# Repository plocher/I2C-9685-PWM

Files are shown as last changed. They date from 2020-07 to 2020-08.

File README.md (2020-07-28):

# I2C-LEDStripDriver
## License: CERN Open Hardware Licence v1.2

I2C 16 channel PWM Driver based on a PCA9685 

The PCA9685 is an I2C-bus controlled 16-channel LED controller optimized for Red/Green/Blue/Amber (RGBA) color backlighting applications.  It can also be used to control Servos.
Each output has its own 12-bit resolution (4096 steps) fixed frequency individual PWM controller

This design, when used in conjunction with the IO4-LED_STRIP driver board, drives RGB + "white" LED strips - I use one set for backdrop lighting (dawn and dusk sunsets...) and the other for overhead (sunlight) valence illumination.

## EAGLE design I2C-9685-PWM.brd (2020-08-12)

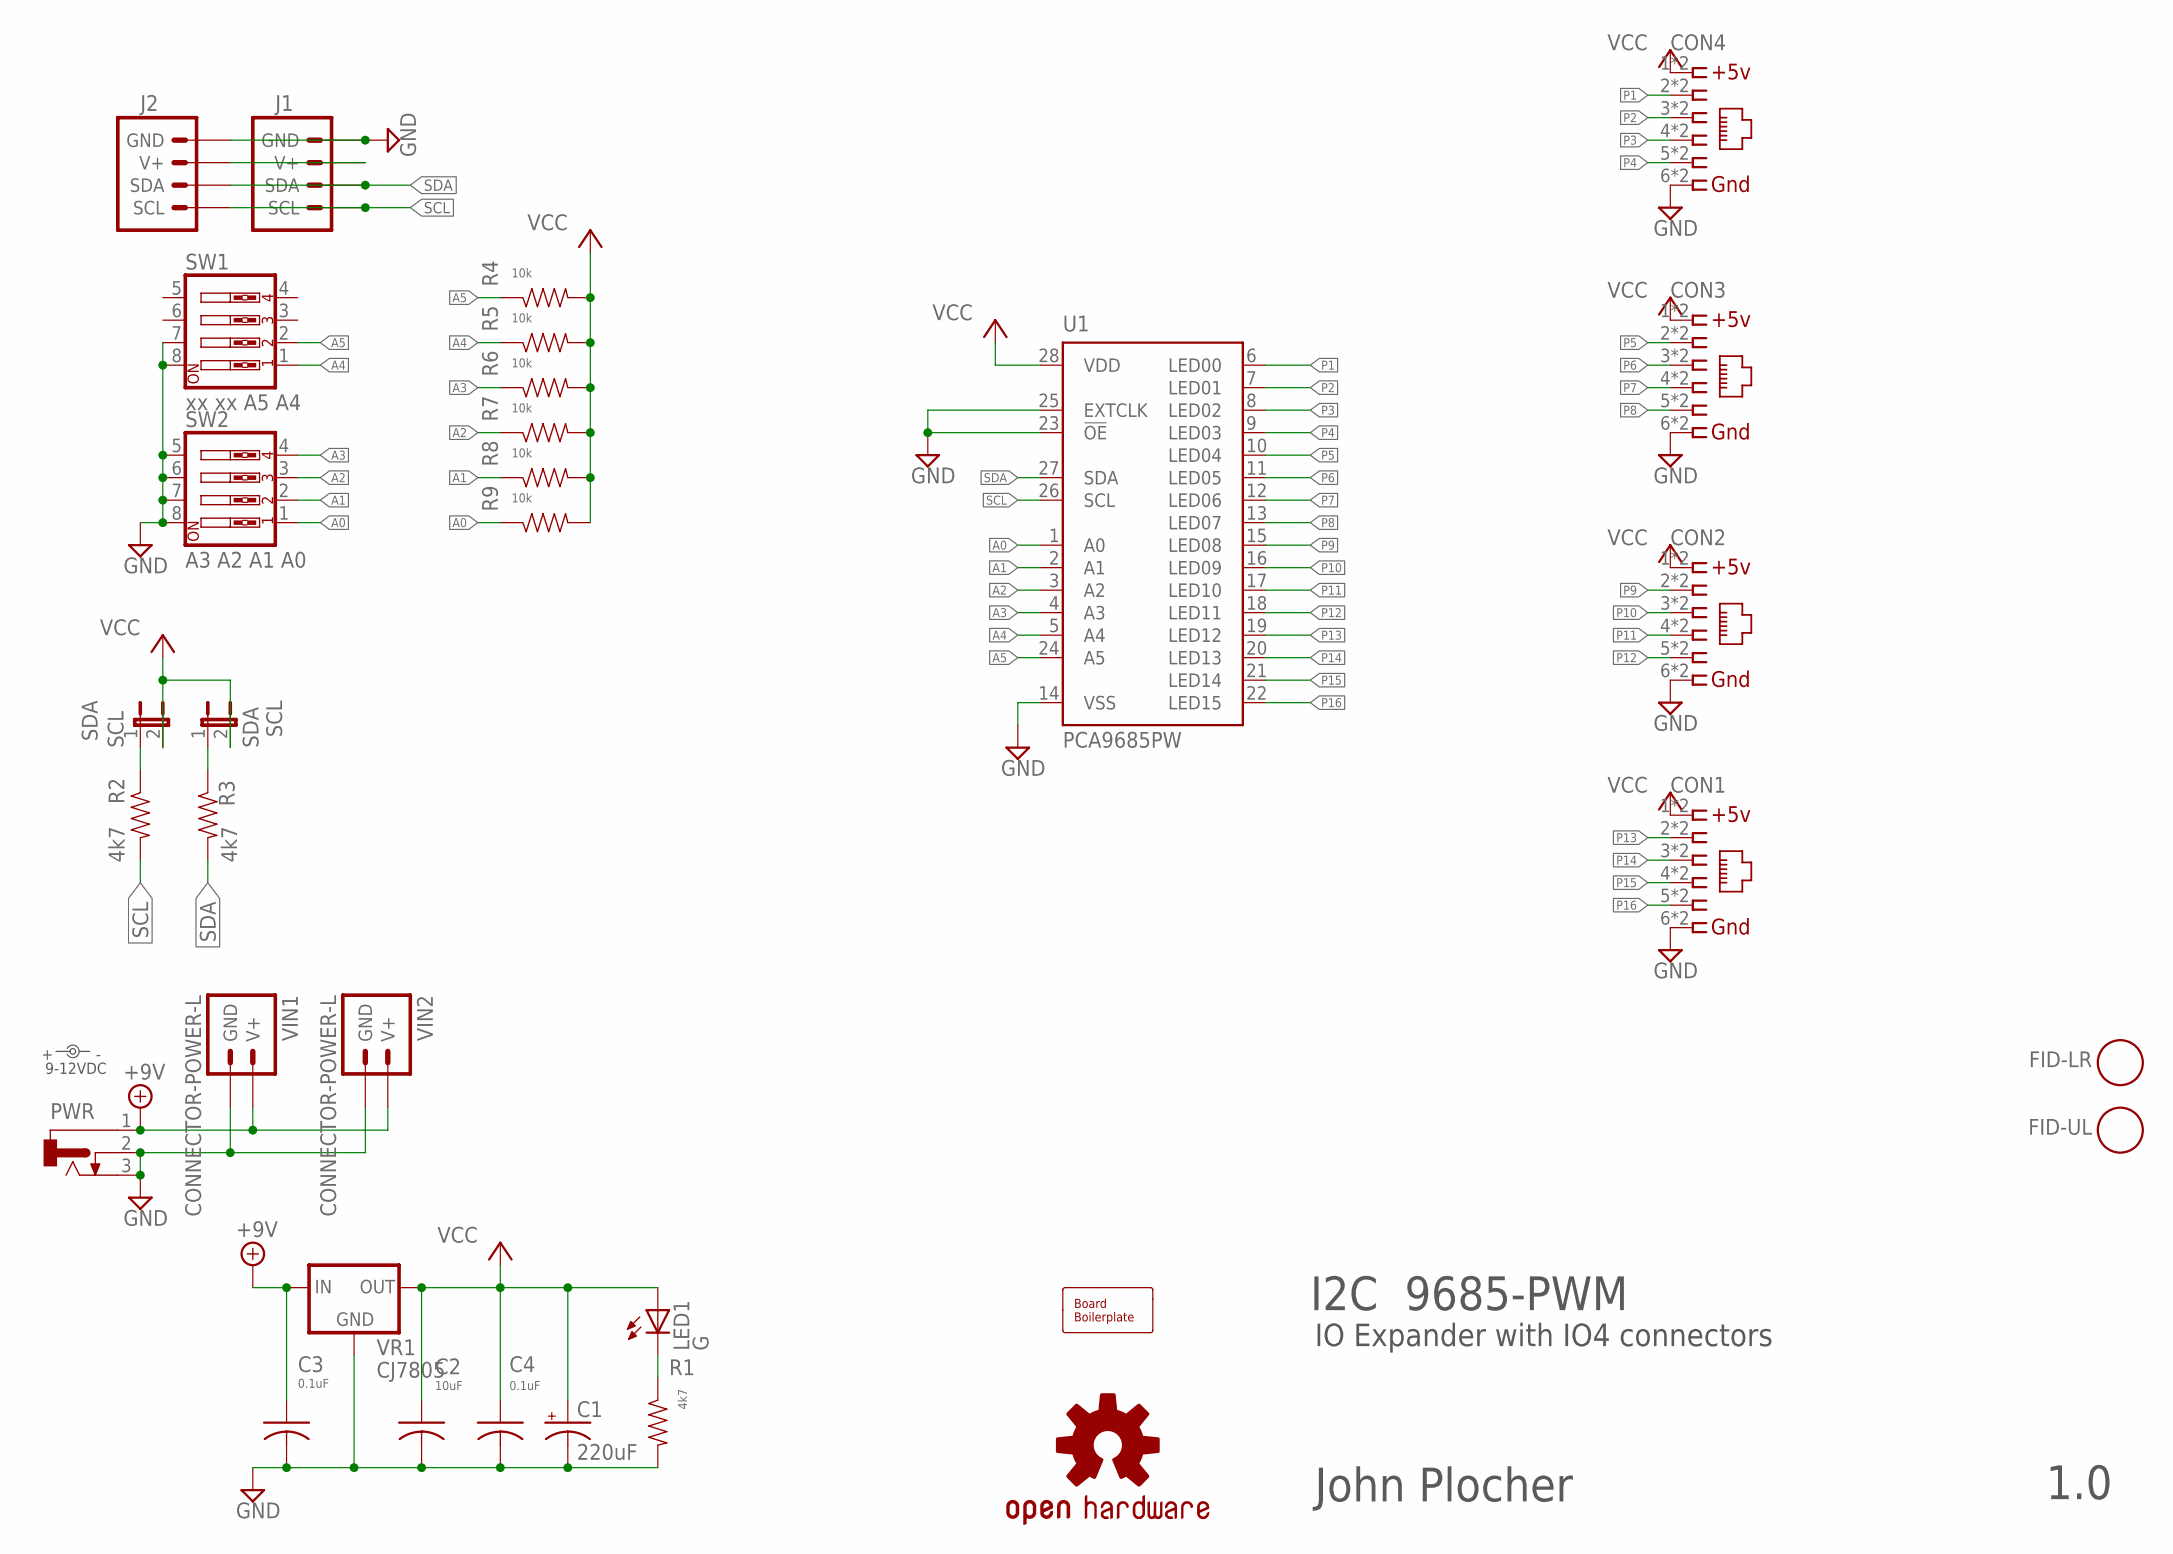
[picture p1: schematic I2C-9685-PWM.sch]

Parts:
BOARD1: BOARD80X100-IOB; BOARD-DINRAIL-3.17IN-IOB
C1: 220uF; 0810-CAP
C2: 10uF; 0805-CAP
C3, C4: 0.1uF; 0805-CAP
CON1, CON2, CON3, CON4: CONNECTOR-IO4IPINS; RJ24-INVERTED-PINS
FID-LR: FIDUCIAL; FIDUCIAL_1MM
FID-UL: FIDUCIAL; FIDUCIAL_1MM
J1, J2: CONNECTOR-I2CLEFT; I2C-L
LED1: G; 0603-LED
PWR: CONNECTOR-DC-POWER-RA; DCJ0202
R1, R2, R3: 4k7; 0603-RES
R4, R5, R6, R7, R8, R9: 10k; 0603-RES
SCL: SDA; 1X02_LOCK
SDA: SCL; 1X02_LOCK
SW1: xx xx A5 A4; EDG-04
SW2: A3 A2 A1 A0; EDG-04
U1: PCA9685PW; TSSOP28
U$1: OSHW-LOGOL; OSHW-LOGO-L
VIN: 9-12VDC; PWR_LABEL
VIN1, VIN2: CONNECTOR-POWER-L; POWER-R2
VR1: CJ7805; TO-252

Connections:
+9V: C3.1, PWR.1, VIN1.V+, VIN1.V+@1 (V+), VIN1.V+@2 (V+), VIN1.V+@3 (V+), VIN2.V+, VIN2.V+@1 (V+), VIN2.V+@2 (V+), VIN2.V+@3 (V+), VR1.1 (IN)
A0: R9.1, SW2.1, U1.1 (A0)
A1: R8.1, SW2.2, U1.2 (A1)
A2: R7.1, SW2.3, U1.3 (A2)
A3: R6.1, SW2.4, U1.4 (A3)
A4: R5.1, SW1.1, U1.5 (A4)
A5: R4.1, SW1.2, U1.24 (A5)
GND: C1.-, C2.2, C3.2, C4.2, CON1.6, CON1.6@1 (6), CON2.6, CON2.6@1 (6), CON3.6, CON3.6@1 (6), CON4.6, CON4.6@1 (6), J1.GND, J1.GND@1 (GND), J2.GND, J2.GND@1 (GND), PWR.2, PWR.3, R1.2, SW1.7, SW1.8, SW2.5, SW2.6, SW2.7, SW2.8, U1.14 (VSS), U1.23 (!OE), U1.25 (EXTCLK), VIN1.GND, VIN1.GND@1 (GND), VIN1.GND@2 (GND), VIN1.GND@3 (GND), VIN2.GND, VIN2.GND@1 (GND), VIN2.GND@2 (GND), VIN2.GND@3 (GND), VR1.2 (GND)
unnamed: LED1.C, R1.1
unnamed: R3.1, SCL.1
unnamed: R2.1, SDA.1
P1: CON4.2, CON4.2@1 (2), U1.6 (LED00)
P2: CON4.3, CON4.3@1 (3), U1.7 (LED01)
P3: CON4.4, CON4.4@1 (4), U1.8 (LED02)
P4: CON4.5, CON4.5@1 (5), U1.9 (LED03)
P5: CON3.2, CON3.2@1 (2), U1.10 (LED04)
P6: CON3.3, CON3.3@1 (3), U1.11 (LED05)
P7: CON3.4, CON3.4@1 (4), U1.12 (LED06)
P8: CON3.5, CON3.5@1 (5), U1.13 (LED07)
P9: CON2.2, CON2.2@1 (2), U1.15 (LED08)
P10: CON2.3, CON2.3@1 (3), U1.16 (LED09)
P11: CON2.4, CON2.4@1 (4), U1.17 (LED10)
P12: CON2.5, CON2.5@1 (5), U1.18 (LED11)
P13: CON1.2, CON1.2@1 (2), U1.19 (LED12)
P14: CON1.3, CON1.3@1 (3), U1.20 (LED13)
P15: CON1.4, CON1.4@1 (4), U1.21 (LED14)
P16: CON1.5, CON1.5@1 (5), U1.22 (LED15)
SCL: J1.SCL, J1.SCL@1 (SCL), J2.SCL, J2.SCL@1 (SCL), R2.2, U1.26 (SCL)
SDA: J1.SDA, J1.SDA@1 (SDA), J2.SDA, J2.SDA@1 (SDA), R3.2, U1.27 (SDA)
V+I2C: J1.V+, J1.V+@1 (V+), J2.V+, J2.V+@1 (V+)
VCC: C1.+, C2.1, C4.1, CON1.1, CON1.1@1 (1), CON2.1, CON2.1@1 (1), CON3.1, CON3.1@1 (1), CON4.1, CON4.1@1 (1), LED1.A, R4.2, R5.2, R6.2, R7.2, R8.2, R9.2, SCL.2, SDA.2, U1.28 (VDD), VR1.3 (OUT)

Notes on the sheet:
I2C 9685-PWM
IO Expander with IO4 connectors
John Plocher
1.0

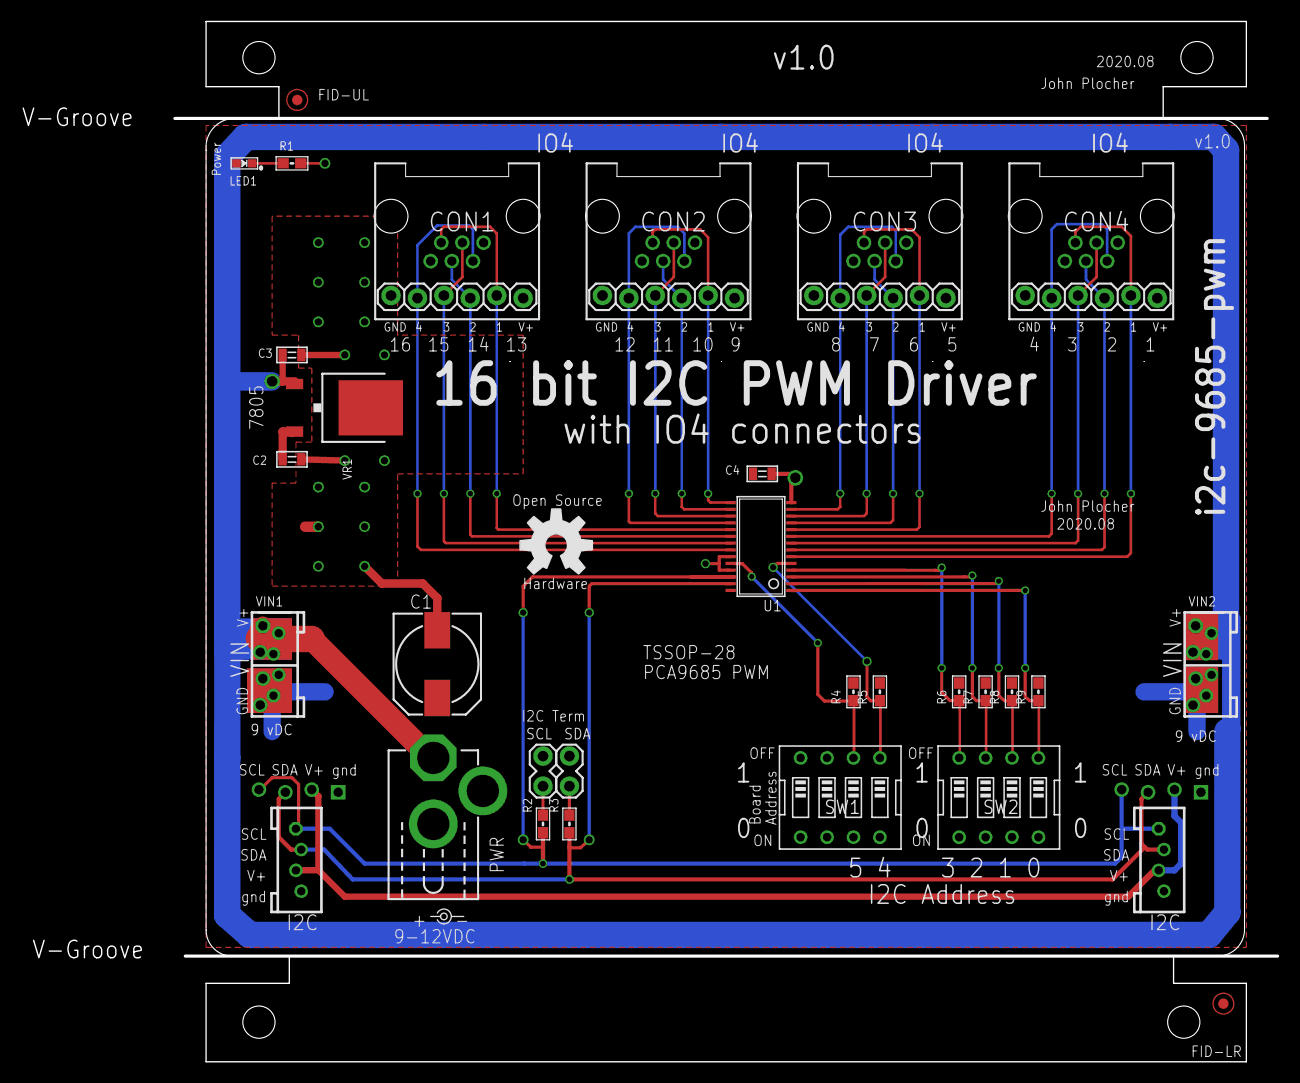
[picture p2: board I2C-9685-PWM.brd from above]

Board: 2 copper layers, 106.0 x 100.0 mm, 34 parts (0 on the bottom side), 31 nets.

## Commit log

2020-07-28 Initial version
    [I2C-9685-PWM.brd, I2C-9685-PWM.sch]
2020-08-02 RR Tracks on back silk, better ground plane
    [I2C-9685-PWM.brd, I2C-9685-PWM.sch]
2020-08-03 better spacing on IO4s and heatsinking on 7805
    [I2C-9685-PWM.brd, I2C-9685-PWM.sch]
2020-08-05 fixed SPCoast lbr part orientation
    [I2C-9685-PWM.brd, I2C-9685-PWM.sch]
2020-08-12 FID placement & names
    [I2C-9685-PWM.brd, I2C-9685-PWM.sch]
